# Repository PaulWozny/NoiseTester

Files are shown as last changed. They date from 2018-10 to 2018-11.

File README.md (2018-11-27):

## Noise tester for voltage regulators

Photo of noise tester
Close-up of noise tester

Borad and software required for tester of noise in power supplies.

This project created to show to show progress in my engineering thesis:

- PL: "Celem pracy jest opracowanie i zbudowanie niskoszumnego układu pozwalającego na pomiar szumów własnych liniowych stabilizatorów napięcia w paśmie do 1 MHz."
- EN: "The goal is to create low noise device which will allow mesure noise of the linear regulatores up to 1MHz"

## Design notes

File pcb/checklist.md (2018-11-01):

### PCB design chcecklist

This document provides reference to evaluate pcb design
 ---
##Design
1. Design is constrained
asdasdas
1.1 asdasd
 
##Schematic 

- All IC are validatated by 
-TX/RX pins are correctly assigned

##PCB
###Footprint
- relay's footprint is not inverted 

###Board
- clerance of PCB shield is sufficient with respect to other components
- testpoint have removed soldermask

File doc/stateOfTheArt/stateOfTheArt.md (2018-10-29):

# Measuring Noise in Voltage Regulators

#### Paweł Woźny </br> Faculty  of Electronics and Telecommunication, AGH 
---

#### Introduction
Following presentation will cover state of the art in current methods of measuring noise generated by regulators. 
In addition, current progress of my work will be shown.

Agenda:

1. What is voltage regulator?
2. What noise regulators have?
3. How to combat them?
4. My progress.

#### Voltage regulator
> is a device which converts unregulated supply to more or less stable output.

Simple regulator with opamp:

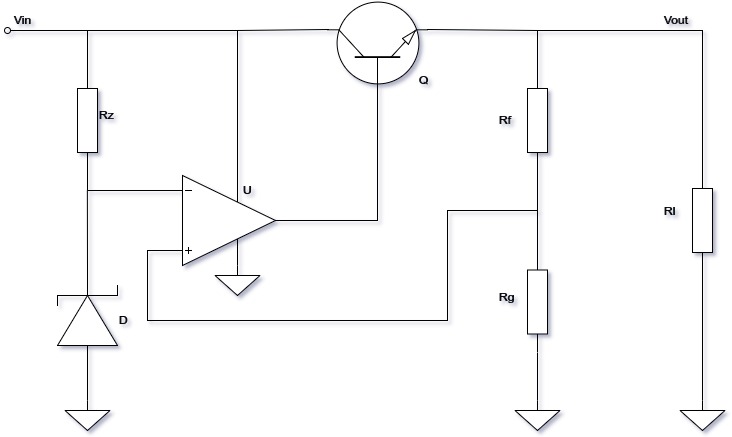
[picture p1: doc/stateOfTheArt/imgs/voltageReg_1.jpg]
aaa


##### Theory of operation

- Voltage reference.
- Feedback network.
- Error amplifier.
- Output stage.
 
#### Sources of noise in circuit

- Intrinsic semiconductor's noises:
    - popcorn noise,
    - shot noise,
    - 1/f (pink)noise.
    - Thermal noise (Johnson, wide-band, white) 
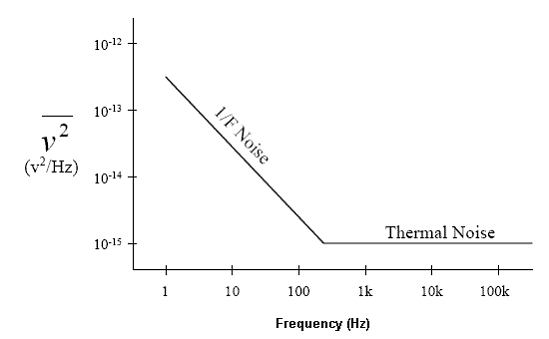
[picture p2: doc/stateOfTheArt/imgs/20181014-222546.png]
    
- Effect of temperature dependency.
- Seebeck (Thermoelectric effect).
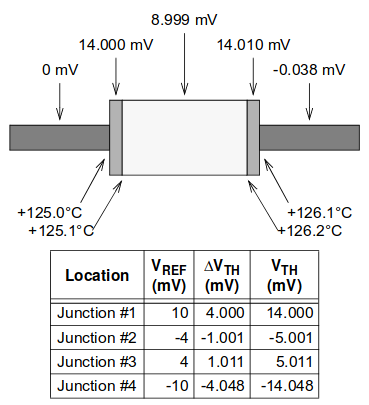
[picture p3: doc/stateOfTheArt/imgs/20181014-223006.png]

- Electromagnetic coupling
- Piezoelectric effects

### Mitigation of noise
- Improving process of lithography.
- Using dynamic offset cancelation (chopper amplifier).
- Using smaller value of resistance:
    - 600 Ohm resistor, 1kHz BW: 0.098uV RMS
    - 50 Ohm resistor, 1kHz BW: 0.0089uV RMS
- Derating elements.
- Filtering the reference:
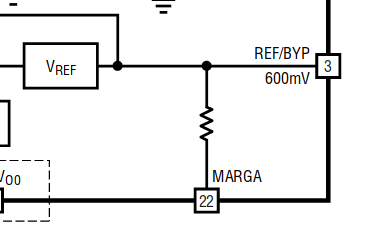
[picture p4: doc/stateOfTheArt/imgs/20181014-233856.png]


### State of the art
Simplified block diagram:


Fully fledged block diagram:
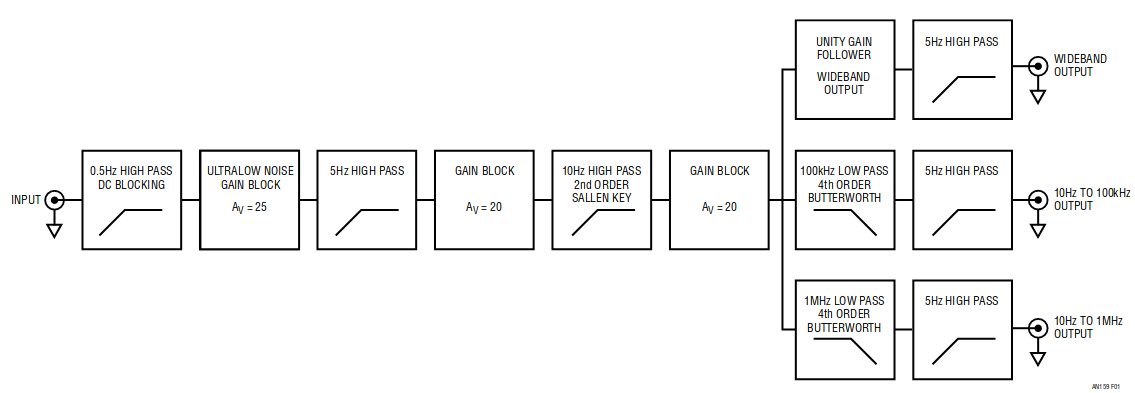
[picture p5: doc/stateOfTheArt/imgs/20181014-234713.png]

</br>

First stage of amplifier:
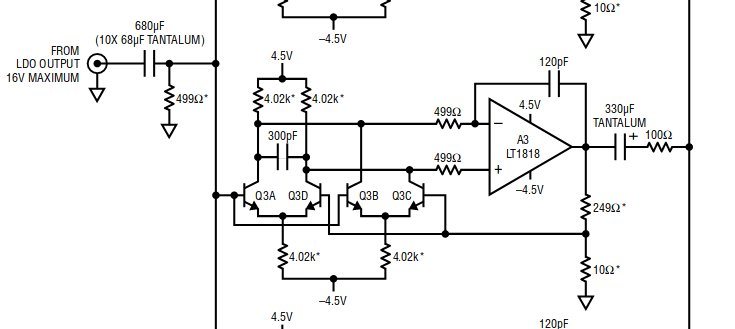
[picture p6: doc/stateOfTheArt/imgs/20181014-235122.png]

</br>

My adaptation:
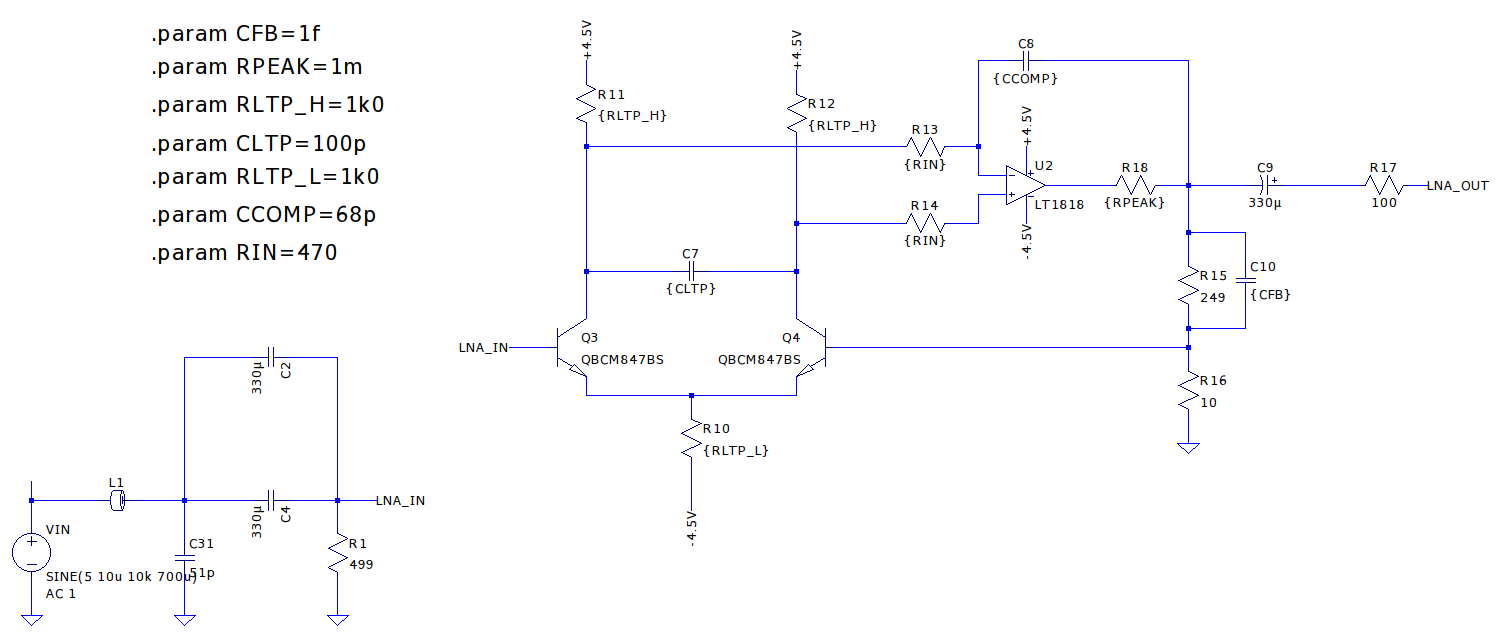
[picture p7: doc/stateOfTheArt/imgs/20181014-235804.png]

</br>

Stability of amplifier:
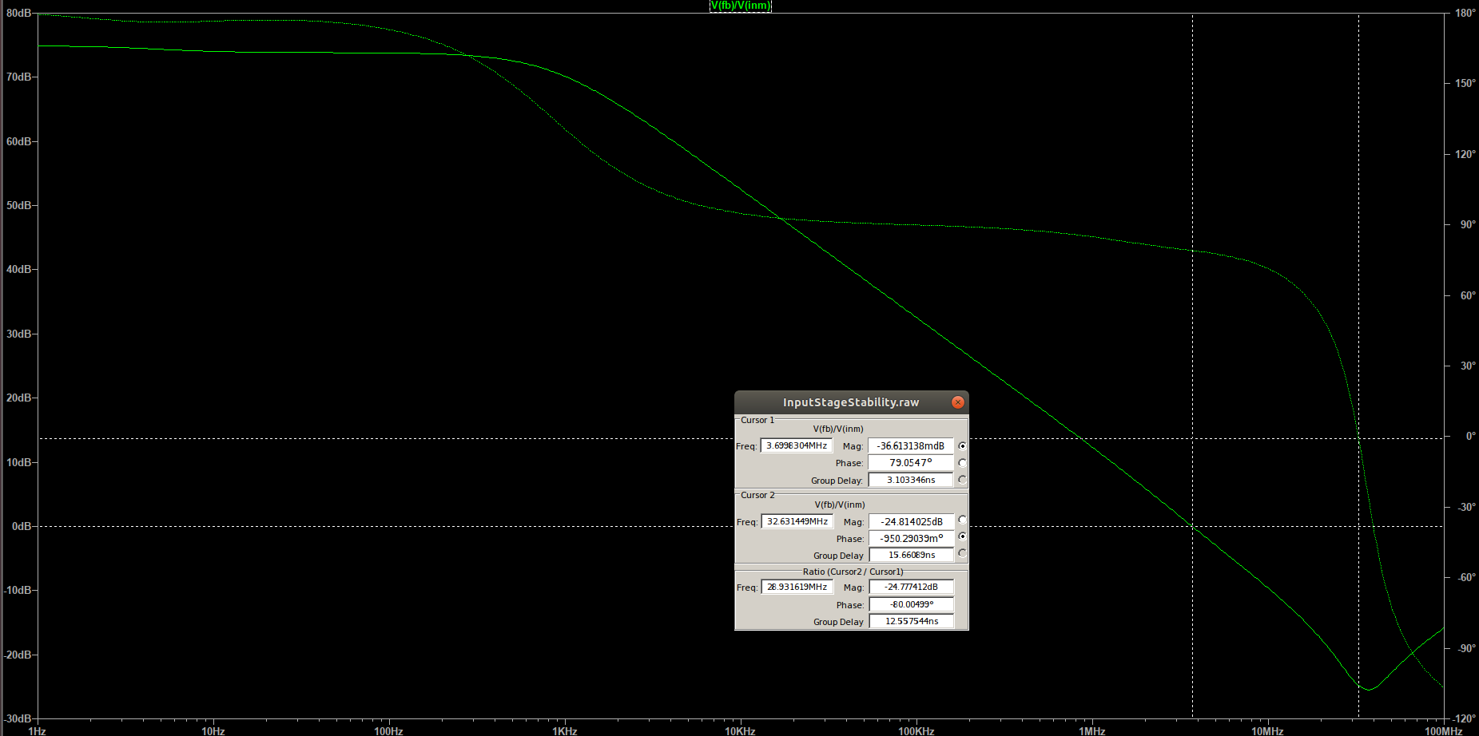
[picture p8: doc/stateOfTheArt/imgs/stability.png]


transfer Function:
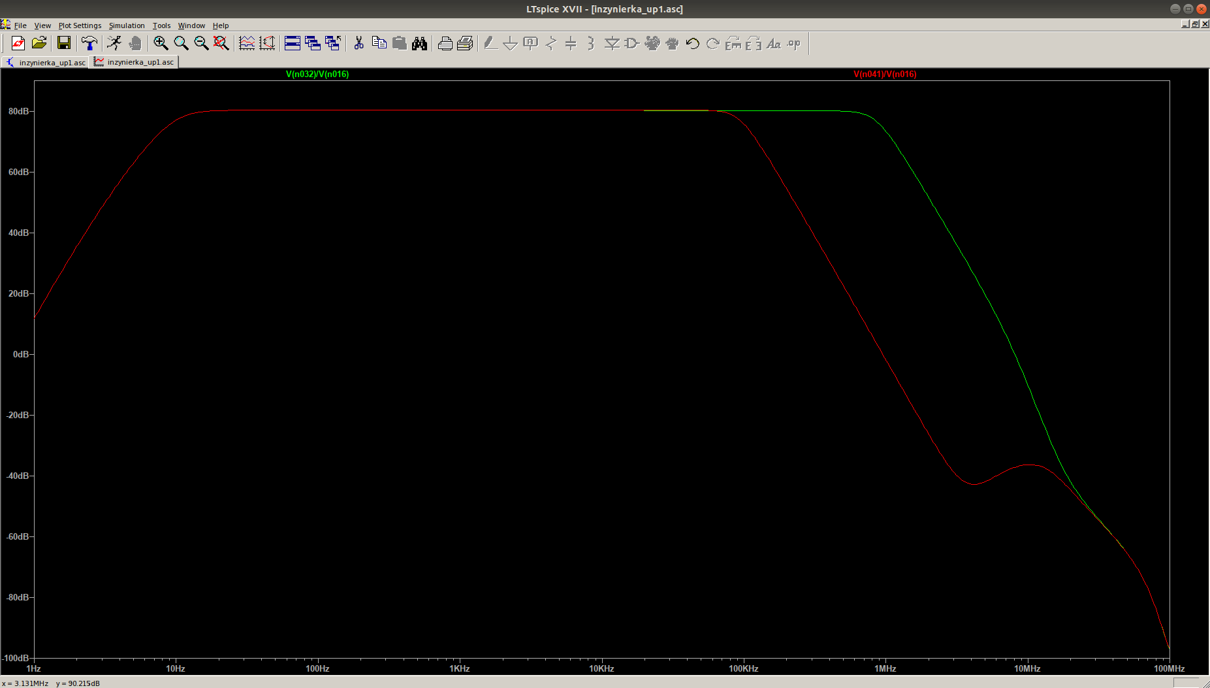
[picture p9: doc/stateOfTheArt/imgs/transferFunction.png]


### ToDo:
- Order components
- create and validate layout
- perform meauserments

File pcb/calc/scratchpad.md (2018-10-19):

#### Nonconstraint text which allow me to convey my thoughts
---
First try: to create discrete analog input stage

https://www.byteparadigm.com/files/documents/Using-SPI-Protocol-at-100MHz.pdf

https://www.ebay.com/itm/DC-DC-Boost-Step-Up-Isolated-Volt-Converter-5V-to-12V-125mA-Power-Supply-Module/323418069670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

http://www.analog.com/media/en/technical-documentation/application-notes/an83f.pdf,

http://www.ti.com/lit/an/snoa387c/snoa387c.pdf

https://www.allaboutcircuits.com/technical-articles/understanding-noise-and-psrr-in-ldos/

http://www.ti.com/lit/ds/symlink/opa1611.pdf

http://www.ti.com/lit/an/slyt133/slyt133.pdf

very useful:
http://www.ti.com/lit/wp/slyy076/slyy076.pdf

po prostu sie nie da uzyc zewnetrznego adc:

- szybki ADC (>40Mbit/s) wymaga szybkiego interfejsu. Niezawodność dostarczania próbek może zapewnić tylko STM
- parę wolnych adceków można zrównoleglić i sterować za pomocą rpi0. tylko tam opóźnienie linuxa jest kurwą i nie otrzyma się powtarzalnych wyników.
- adcek zintegrowany w stm32 będzie szumił, a do tego będzie problem z izolacją toru pomiarowego

Moja propozycja:

- Rpi0 łączy się z FTDI HS, który łączy się przez izolator z ADC przez SPI, który jest sterowany z AFE. FTDI wyprowadza gpio potrzebne do sterowania afe

lub:

- afe - adc - iso - stm32/w usb, ram, sd

pierdułki dla kicada
https://knowledge.autodesk.com/support/autocad-electrical/learn-explore/caas/CloudHelp/cloudhelp/2019/ENU/AutoCAD-Electrical/files/GUID-7871E6EF-24D5-467E-9B74-321FE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

---
tutaj należałoby skomasować swoje przemyślenia:
xxxxx
---
4.10.2018

Pod tym linkiem znajduje się ulepszona wersja układu od jima:
http://www.analog.com/media/en/technical-documentation/application-notes/an159fa.pdf

- Mają drogie tranzystory na stopniu wejściowym: THAT300A. kosztuje około 45plz/sztukę, a potrzeba przynajmniej 4.
Łączą dwie pary różnicowe równolegle. W pdfie pd czecha {{}}} było pokazane, że to może wpłynąć negatywnie na {{{{{}}}}}
- Sama para różnicowa jest mocno dopasowane. Ciekawe czy dałoby się użyć tańszych elementów przy zastosowaniu aktywnej kompensacji, jak tutaj:
http://www.analog.com/media/en/technical-documentation/application-notes/an124f.pdf
Na przykład 
- Używają kondensatory tantalowe, które nie mają efektu piezo. Tylko trzeba uważać, żeby nie wybuchły

Porównując dshety:
https://assets.nexperia.com/documents/data-sheet/BCM847BV_BS_DS.pdf
oraz
http://www.thatcorp.com/datashts/THAT_300-Series_Datasheet.pdf
wychodzi na to, że aż tak bardzo się nie różnią. THAT300 ma dopasowanie hfe na poziomie 4% vs 10% od BCM847BV, natomiast dopasowanie VBE THAT300 ma 3mV max z 0.5 typowym, a BCM847 ma** 2mV MAX**.

---
6.10.2018

Stworzyłem cały schemat dla wzmacniacza. Od razu wiedzę --2-- trzy problemy

- Obudowa. Jeżeli będzie zrobiona ze stali (a stal jest najtańsza) to ścianka musi być gruba na 10-15mm
https://allegro.pl/blacha-stalowa-10-mm-cieta-na-wymiar-i6728885673.html
- stabilność wzmacniacza. Jest dużo stopni wzmacniacza i każdy może oscylować. ;/
- małe napięcie wyjsciowe. Napięcie wyjściowe dla wejścia 1uV wynosi 10mV. przydałyby się kolejne stopnie wzmocniania dla obróbki z ADCkiem

Zasilanie bateryjne mogą zapewnić baterie R20.
https://allegro.pl/koszyk-na-baterie-3xr20-plaski-i7416083768.html 

Tranzystory uzyte przeze mnie mają inne pojemności od THATowych. PRzez co musiałem pozmieniać układ

Czy dwa kondensatory tantalowe 330uF będą miały takie same (albo przynajmniej wystarczające) właściwośći przy granicy 1MHz?
TAJE337M016RNJ

Zamiast 2 330stek można użyć trzy 220uF

Albo 100u faradowe:  T491D107K020AT (dostępne w TME)

Koszt samych  kondensatorów to około 100pln

---
7.10.2018

Skoczyłem układ. No nie do końca bo jest niestabilny. Przy dodaniu czwartego stopnia wejściowego dostaje oscylacji koło 13MHz. Zrobiłem projekt ze samym stopniem wejściowym i zaczynam poszukiwania
Wygląda na to, że gdy podłączam wejście od 4. układu to całość dostaje pierdolca.
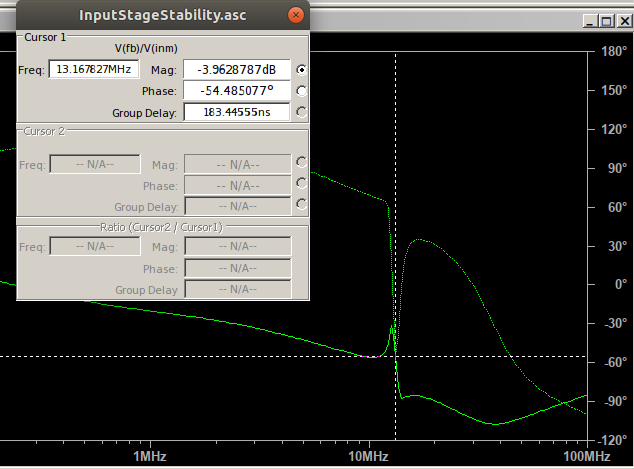
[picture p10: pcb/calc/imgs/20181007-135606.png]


Problem okazał się dolny rezystor. Zmiana z 1k do 3k pomogła.
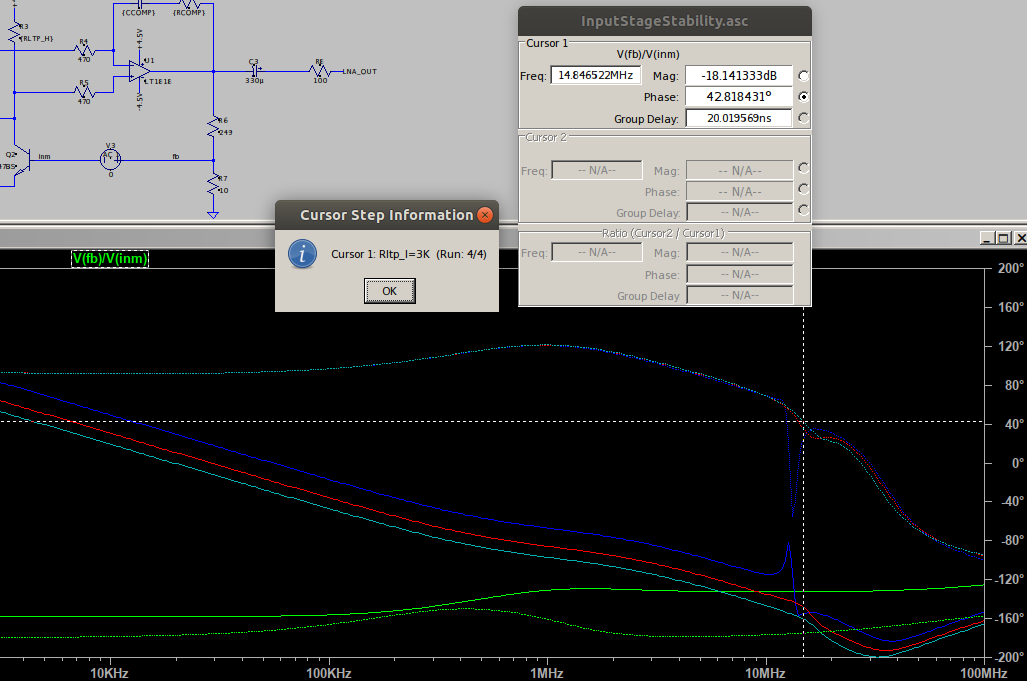
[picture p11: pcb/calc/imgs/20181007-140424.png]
 

Udało się! Nie oscyluje i ma xxx marginesu

Podczas Różnorakich testów można było zauważyć, że łatwo nasycić wzmacniacz. Może dodać możliwość zmiany wzmocnienia ostatniego bloku?
 
 - 100Ohm/2k
 - 100Ohm/100Ohm
 
 Symulacja tran dla przemiatanej czestotliwości wykazała, że wzmocnienie spada ?liniowo? ze wzrostem czestotliowści. Dla f=650kHz wzmocnienie było równe tylko 0.560 wartości początkowej.
 
 Przez tą kompensacje przysiadło trochę wzmocnienie
 
 bawiąc się .tep zauważyłem, że można symulować do trzeb zmiennych jednocześnie. Fajnie by było jakbym znalazł możliwość automatycznego wybierania pożądanych charakterystyk; np w moim przypadku interesują mnie tylko te wartośći, dla których wzmocnienie przyy 1MHz jest równe 28dB
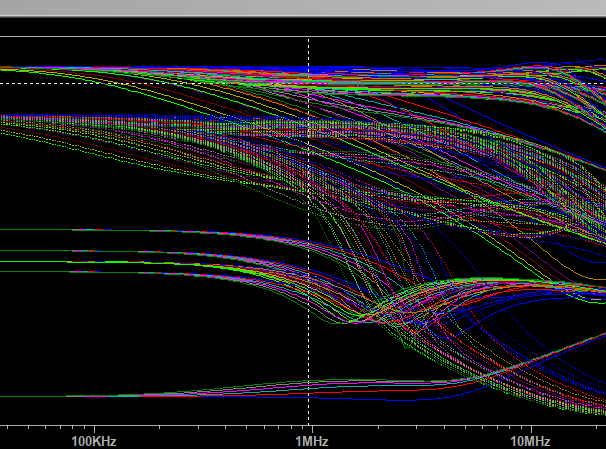
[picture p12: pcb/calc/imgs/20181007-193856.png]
 
 
 Ostateczny wynik stabilności:
 
 Schemat układu:
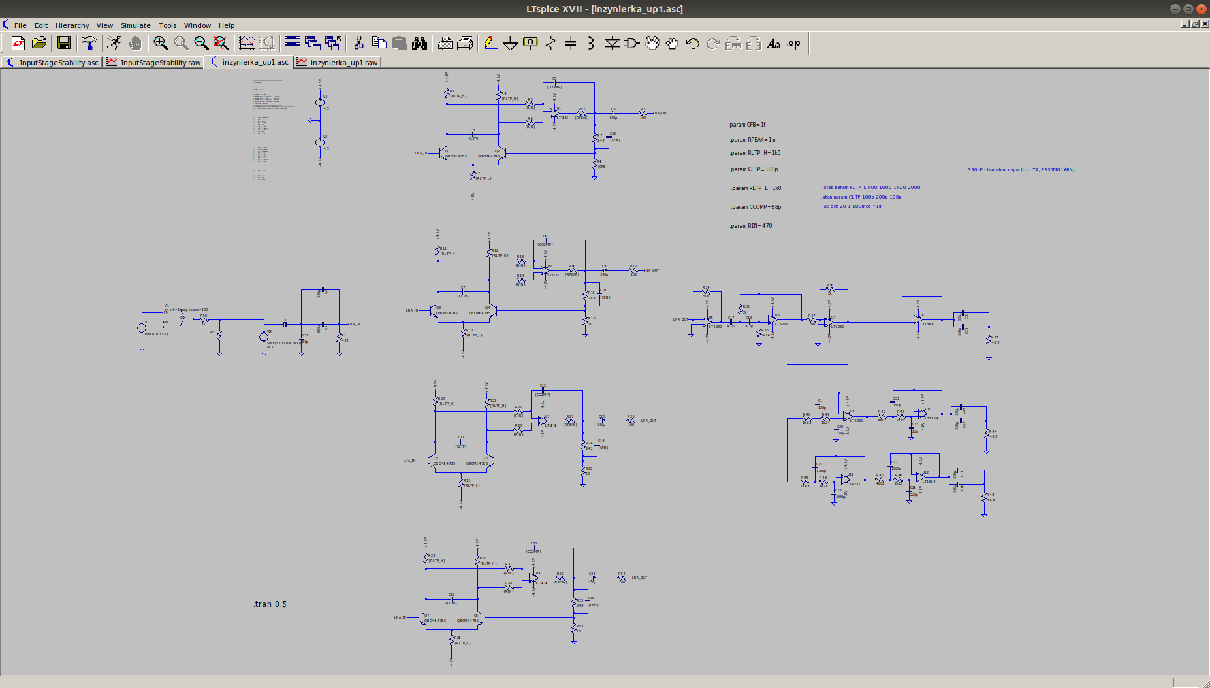
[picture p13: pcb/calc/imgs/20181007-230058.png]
 
 
 Lista zakupów:
 
 - precyzyjne rezystory 1k:  MORNTA1001AT5 - 4 sztuki
 - rezystory do FB 250Ohm/10Ohm: Coś z elpoda 0.25%/10ppm 4 sztuki
 asd

 as

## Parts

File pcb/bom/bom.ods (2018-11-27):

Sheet: BOM
co | ilosć | cena jed | razem | skąd
Tantale 220uF | 60 | 0,615 | 36,9 | https://allegro.pl/10szt-220uf-10v-d-tantal-smd-kondensator-s-m-i7288054184.html
LT1364CS8 | 5 | 11 | 55 | https://allegro.pl/lt1364cs8-soic8-i7589381160.html
LT1818 | 5 | 7,8 | 39 | digikey
LT6232 | 3 | 31,2 | 93,6 | digikey
 |  |  | 0
 |  |  | 0
 |  |  | 0
 |  |  | 0
 |  |  | 0
 |  |  | 0
 |  |  | 0
 |  |  | 0
 |  |  | 0
 |  |  | 0
 |  |  | 0
 |  |  | 0
suma |  |  | 224,5

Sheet: paid
Tantals 220uF | 45,89
LT1364 | 63,99
koszyk na R20 | 32,19
PCB | 250
Elementy | 277
suma | 669,07

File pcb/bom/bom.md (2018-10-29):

# niedziela, 28. października 2018 08:49

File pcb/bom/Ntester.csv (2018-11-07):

Id | Designator | Package | Quantity | Designation | Supplier and ref
1 | J6,J3,J2,J5 | BNC_TEConnectivity_1478204_Vertical | 4 | 5-1634503-1
4 | R36,R31,R26,R2 | R_0603_1608Metric | 4 | RNCF0603AKT10R0
5 | C77,C66,C55,C8 | R_0603_1608Metric | 4 | 885012006038
6 | C86,C87,C78,C80,C75,C76,C69,C67,C56,C58,C64,C65,C41,C40,C27,C26,C21,C20,C5,C4,C16,C15,C11,C10 | R_0603_1608Metric | 24 | 0603B104M500CT
7 | R34,R33,R29,R28,R23,R24,R5,R4 | R_0603_1608Metric | 8 | CR0603-JW-471ELF
8 | C79,C68,C57,C44,C43,C2,C9 | R_0603_1608Metric | 7 | 885012006007
9 | RN4,RN3,RN2,RN1 | R_Array_Convex_4x1206 | 4 | ACASA1001S1001P1AT
12 | R35,R30,R25,R1 | R_0603_1608Metric | 4 | RNCF0603TKY250R
13 | Q4,Q3,Q2,Q1 | SOT-363_SC-70-6 | 4 | BC847BDW1T1G
14 | R37,R32,R27,R6 | R_0603_1608Metric | 4 | RG1608N-101-W-T1
15 | U7,U6,U5,U1 | SOIC-8-LINEAR | 4 | LT1818
16 | C47,C54,C53,C52,C51,C50,C49,C48,C46,C45,C38,C37,C36,C35 | C_1210_3225Metric | 14 | GRM32ER60J107ME20K
22 | SW1 | SW_CuK_JS202011CQN_DPDT_Straight | 1 | JS202011CQN
23 | C29,C24 | CAP-6054-SMDTD04470YA00MT00 | 2 | SMDTD04470YA00MT00
26 | D4,D3,D2,D1 | SOT-23 | 4 | BAS116LT1G
28 | R3 | R_2512_6332Metric | 1 | RHC2512FT4R99
29 | R9,R10 | R_0603_1608Metric | 2 | RMCF0603FT499R
30 | U3,U2 | SOIC-8-LINEAR | 2 | LT6231
31 | R8 | R_1206_3216Metric | 1 | CR1206-FX-4990ELF
32 | R7 | R_2512_6332Metric | 1 | CRM2512-JW-470ELF
36 | FB1 | R_0603_1608Metric | 1 | 742792651
39 | J7 | Wuerth_36503505_50x50mm | 1 | 36503505S
 |  |  |  | 36003500S

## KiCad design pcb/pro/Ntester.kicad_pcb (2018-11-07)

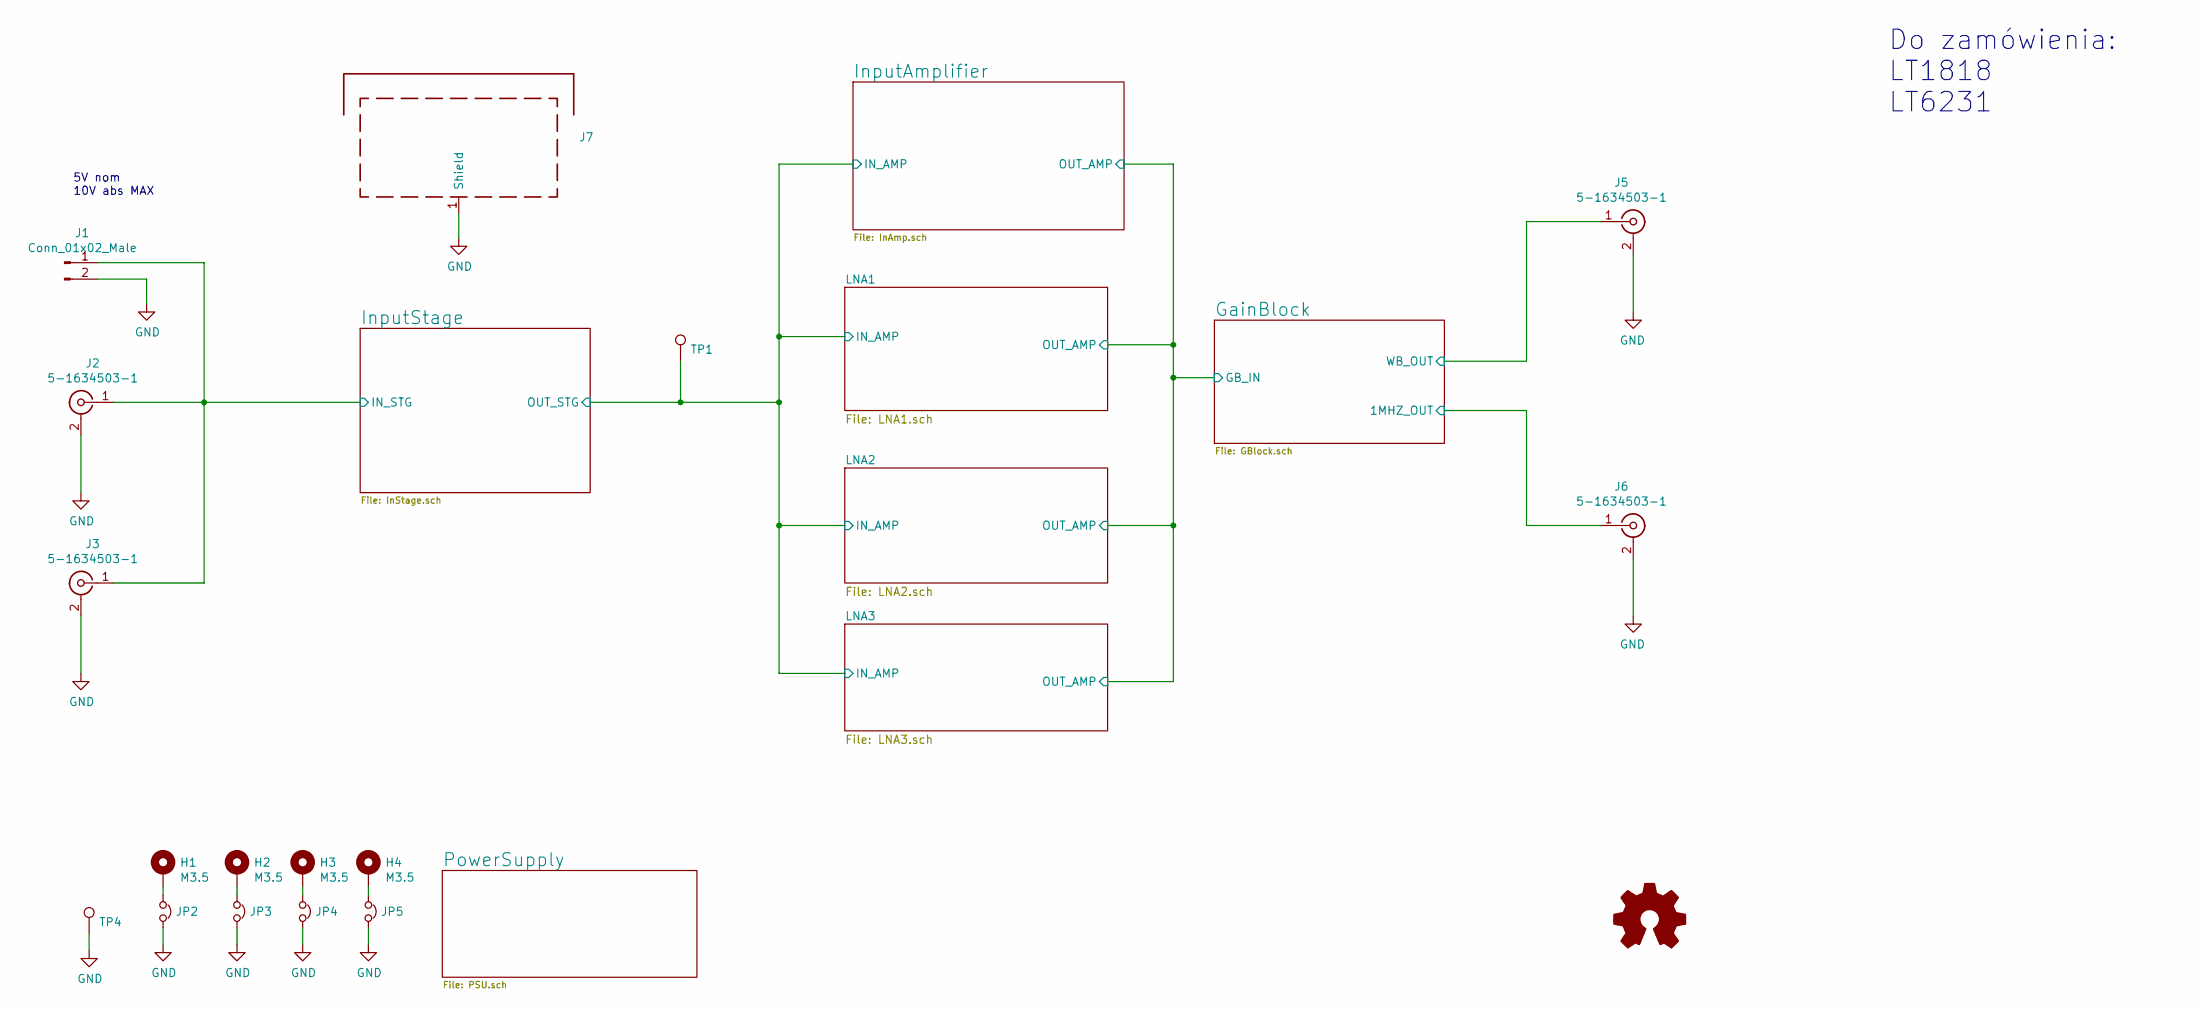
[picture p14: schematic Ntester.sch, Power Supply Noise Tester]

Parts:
H1, H2, H3, H4: M3.5; MountingHole_3.5mm_Pad_Via
J1: Conn_01x02_Male; PinHeader_1x02_P2.54mm_Vertical
J2, J3, J5, J6: 5-1634503-1; BNC_TEConnectivity_1478204_Vertical
J7: 36503505S 36003500S; Wuerth_36503505_50x50mm
JP2, JP3, JP4, JP5: GND_SHIELD; SolderJumper-2_P1.3mm_Open_TrianglePad1.0x1.5mm
TP1, TP4: TestPoint; TestPoint_THTPad_D1.0mm_Drill0.5mm

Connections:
/GainBlock/1MHZ_OUT: J6.1 (In); also elsewhere on the board
/GainBlock/WB_OUT: J5.1 (In); also elsewhere on the board
/InputAmplifier/IN_AMP: TP1.1; also elsewhere on the board
/InputStage/IN_STG: J1.1, J2.1 (In), J3.1 (In); also elsewhere on the board
GND: J1.2, J2.2 (Ext), J3.2 (Ext), J5.2 (Ext), J6.2 (Ext), J7.1, JP2.2, JP3.2, JP4.2, JP5.2, TP4.1; also elsewhere on the board
unnamed: H1.1, JP2.1
unnamed: H2.1, JP3.1
unnamed: H3.1, JP4.1
unnamed: H4.1, JP5.1

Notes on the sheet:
5V nom 10V abs MAX
Do zamówienia: LT1818 LT6231

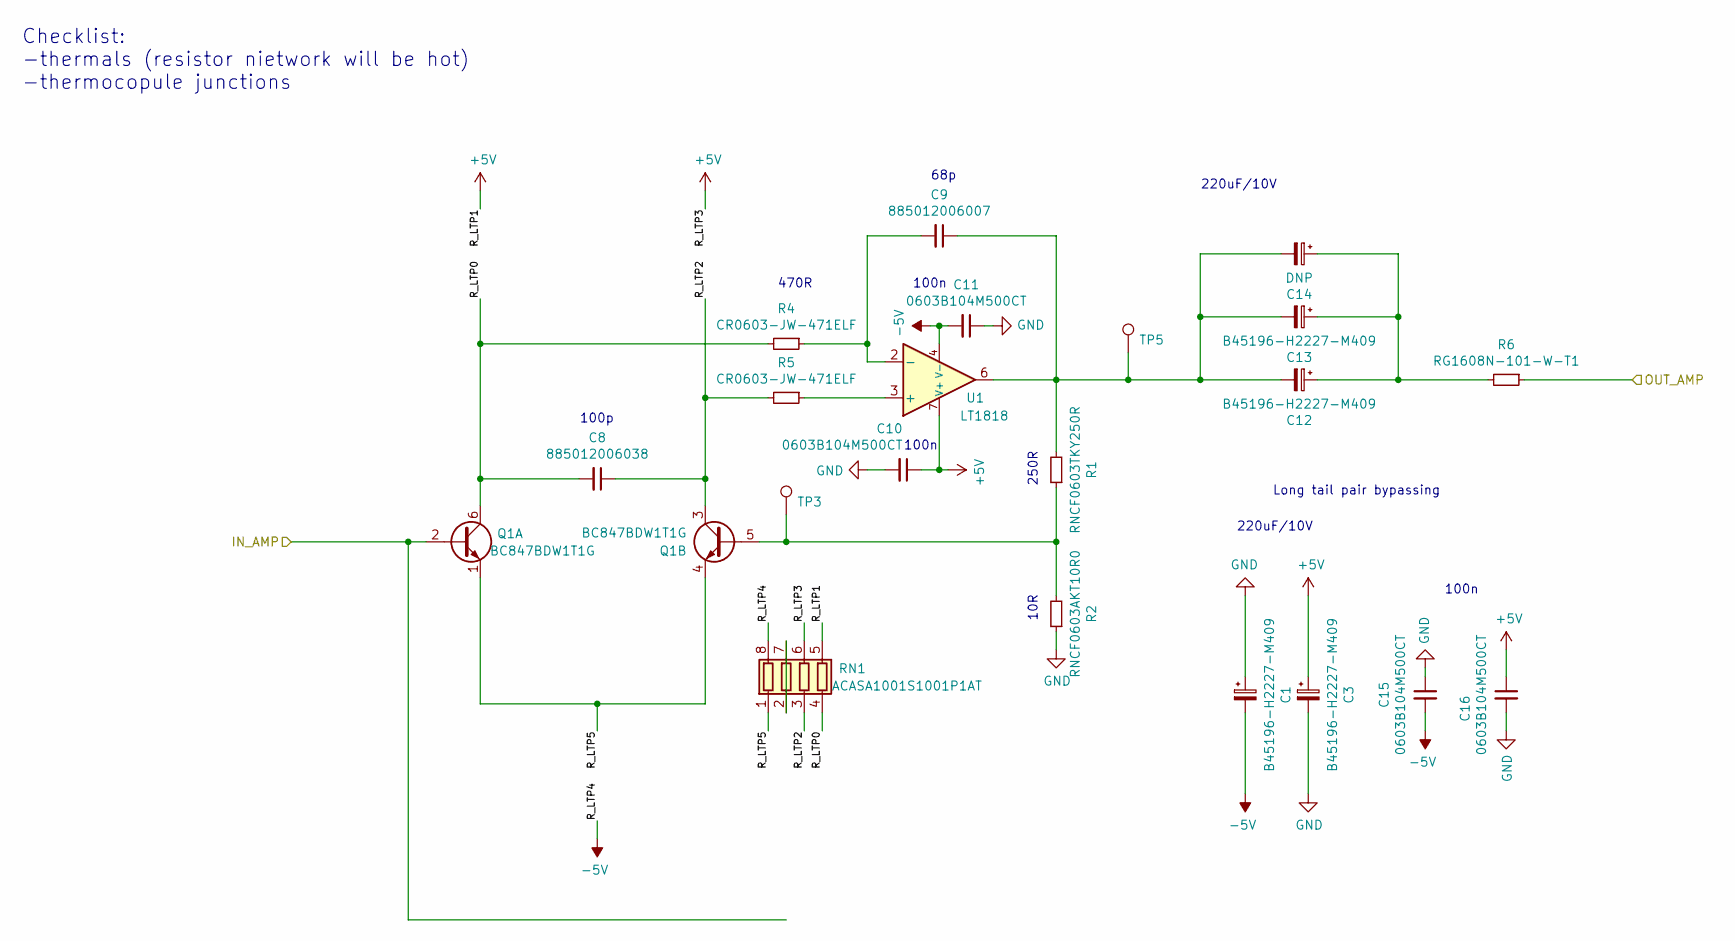
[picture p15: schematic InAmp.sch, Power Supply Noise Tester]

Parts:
C1, C3, C12, C13: B45196-H2227-M409; CP_EIA-7343-31_Kemet-D
C8: 885012006038; R_0603_1608Metric
C9: 885012006007; R_0603_1608Metric
C10, C11, C15, C16: 0603B104M500CT; R_0603_1608Metric
C14: DNP; CP_EIA-7343-31_Kemet-D
Q1: BC847BDW1T1G; SOT-363_SC-70-6
R1: RNCF0603TKY250R; R_0603_1608Metric
R2: RNCF0603AKT10R0; R_0603_1608Metric
R4, R5: CR0603-JW-471ELF; R_0603_1608Metric
R6: RG1608N-101-W-T1; R_0603_1608Metric
RN1: ACASA1001S1001P1AT; R_Array_Convex_4x1206
TP3, TP5: TestPoint; TestPoint_THTPad_D1.0mm_Drill0.5mm
U1: LT1818; SOIC-8-LINEAR

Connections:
+5V: C3.1, C10.1, C16.1, RN1.5 (R4.2), RN1.6 (R3.2), U1.7 (V+); also elsewhere on the board
-5V: C1.2, C11.2, C15.2, RN1.8 (R1.2), U1.4 (V-); also elsewhere on the board
/GainBlock/GB_IN: R6.1; also elsewhere on the board
/InputAmplifier/IN_AMP: Q1.2 (B1); also elsewhere on the board
/InputAmplifier/R_LTP0: C8.2, Q1.6 (C1), R4.2, RN1.4 (R4.1)
/InputAmplifier/R_LTP2: C8.1, Q1.3 (C2), R5.2, RN1.3 (R3.1)
/InputAmplifier/R_LTP5: Q1.1 (E1), Q1.4 (E2), RN1.1 (R1.1)
GND: C1.1, C3.2, C10.2, C11.1, C15.1, C16.2, R2.1; also elsewhere on the board
unnamed: C9.2, R4.1, U1.2 (-)
unnamed: C12.1, C13.1, C14.1, R6.2
unnamed: C9.1, C12.2, C13.2, C14.2, R1.2, TP5.1, U1.6
unnamed: Q1.5 (B2), R1.1, R2.2, TP3.1
unnamed: R5.1, U1.3 (+)

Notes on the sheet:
Checklist: -thermals (resistor nietwork will be hot) -thermocopule junctions
Long tail pair bypassing
100n
220uF/10V
68p
100p
470R
10R
250R

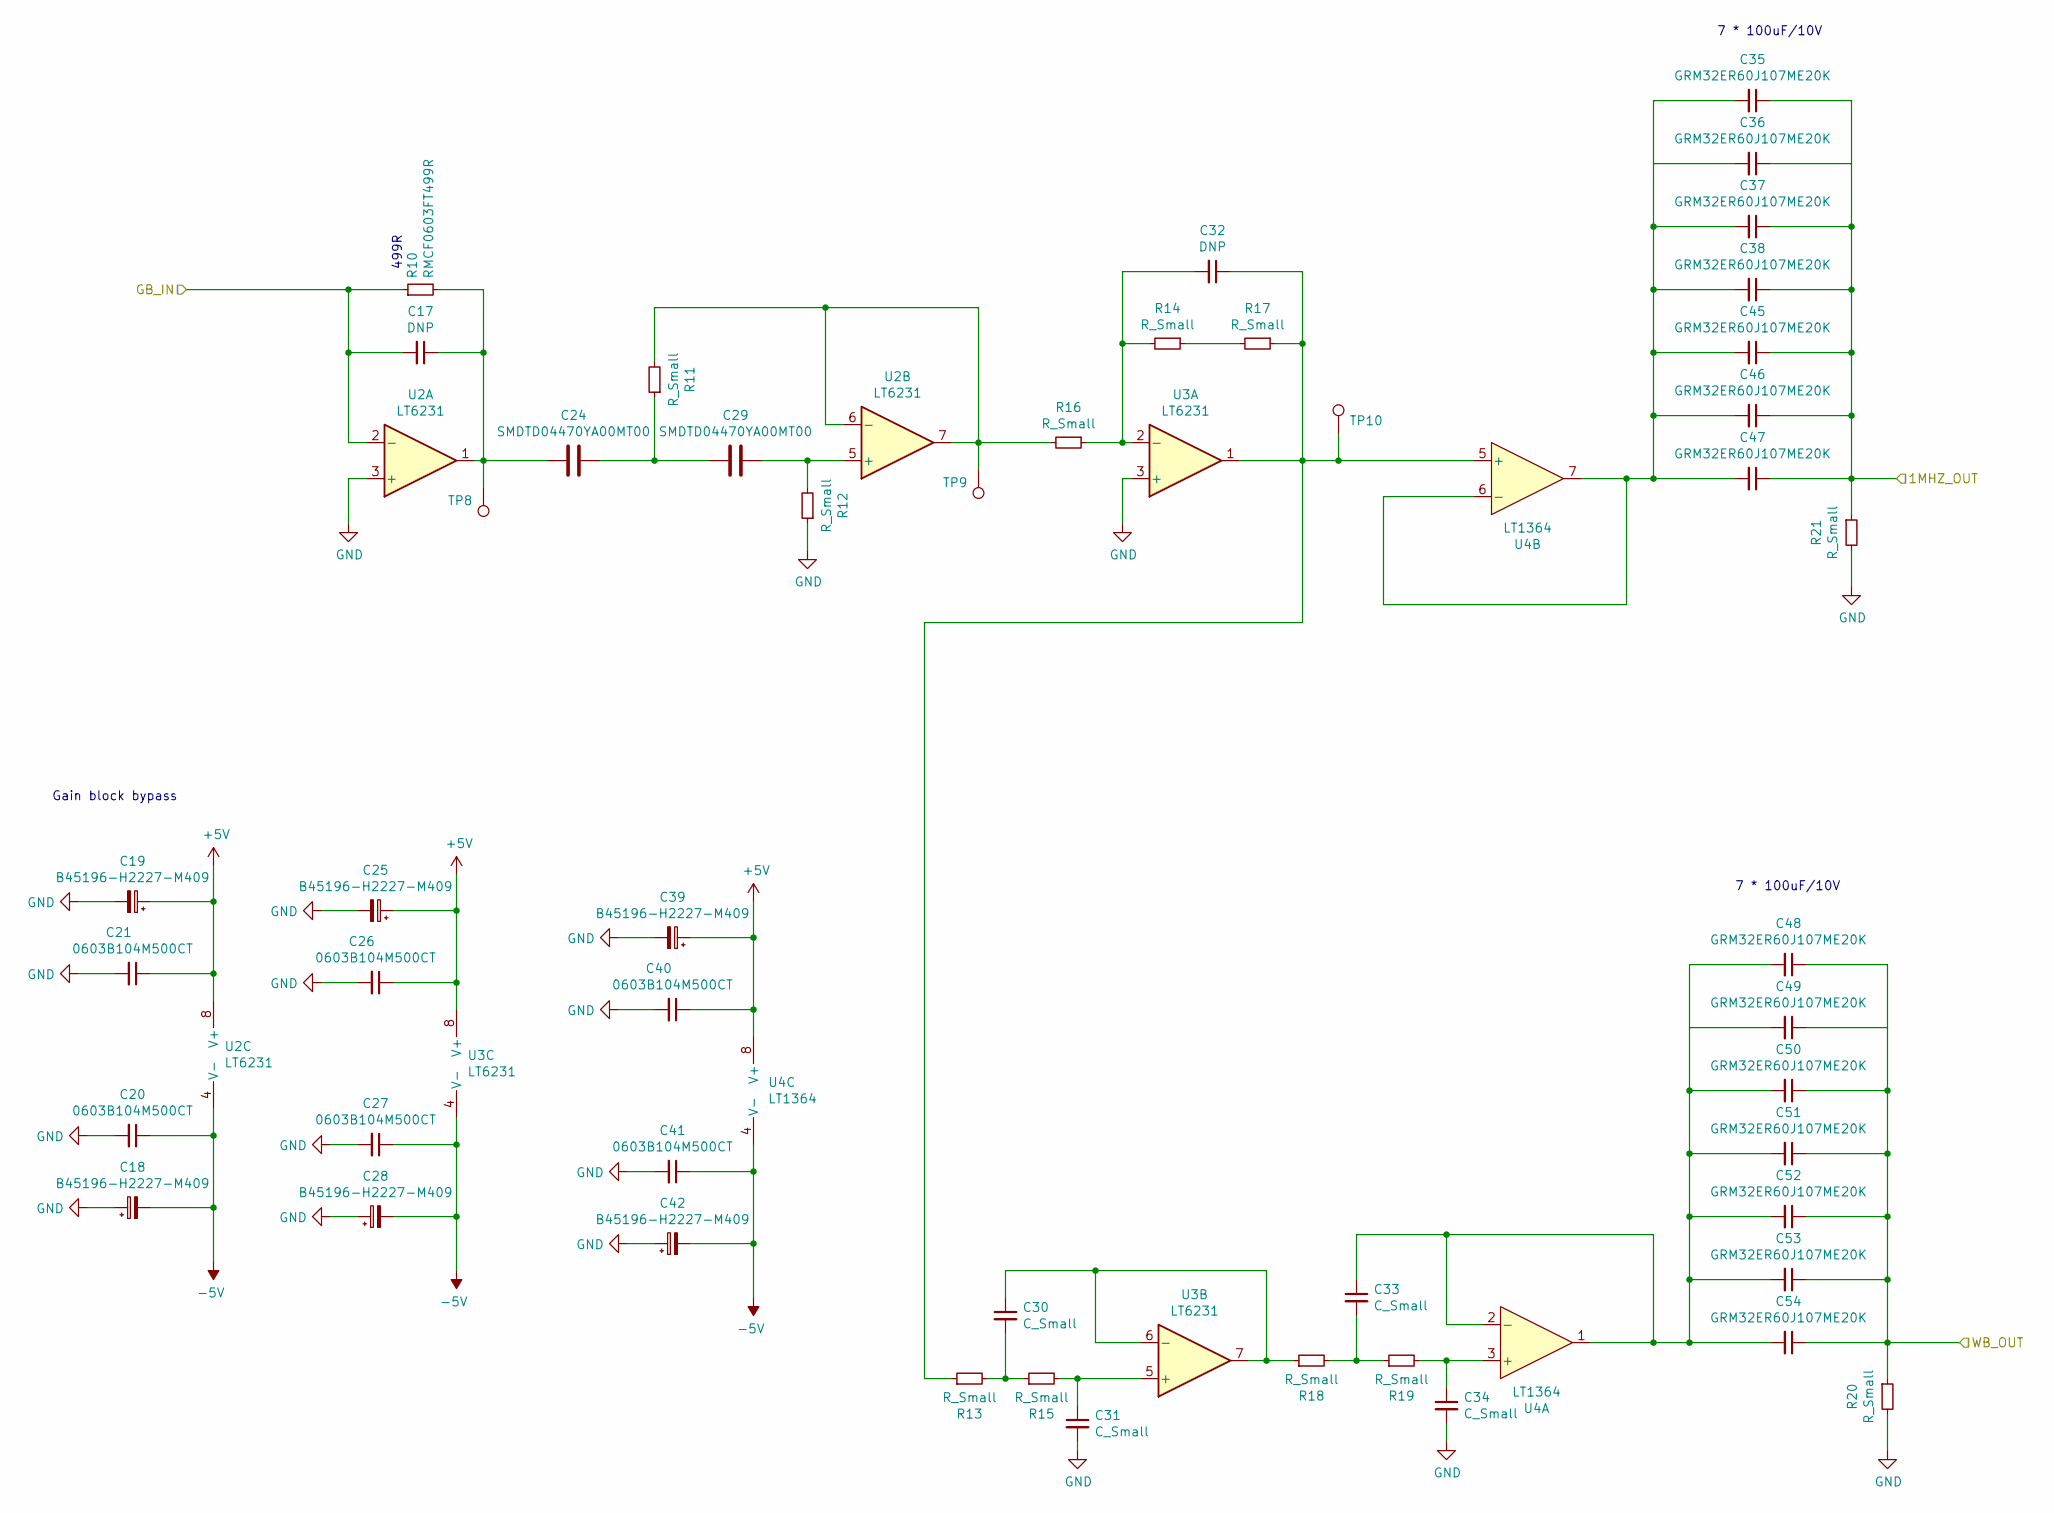
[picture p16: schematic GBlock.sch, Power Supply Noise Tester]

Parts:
C17, C32: DNP; C_0603_1608Metric
C18, C19, C25, C28, C39, C42: B45196-H2227-M409; CP_EIA-7343-31_Kemet-D
C20, C21, C26, C27, C40, C41: 0603B104M500CT; R_0603_1608Metric
C24, C29: SMDTD04470YA00MT00; CAP-6054-SMDTD04470YA00MT00
C30, C31, C33, C34: C_Small; C_0603_1608Metric
C35, C36, C37, C38, C45, C46, C47, C48, C49, C50, C51, C52, C53, C54: GRM32ER60J107ME20K; C_1210_3225Metric
R10: RMCF0603FT499R; R_0603_1608Metric
R11, R12, R13, R14, R15, R16, R17, R18, R19: R_Small; R_0603_1608Metric
R20, R21: R_Small; R_1206_3216Metric
TP8, TP9, TP10: TestPoint; TestPoint_THTPad_D1.0mm_Drill0.5mm
U2, U3: LT6231; SOIC-8-LINEAR
U4: LT1364; SOIC-8-LINEAR

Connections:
+5V: C19.1, C21.1, C25.1, C26.1, C39.1, C40.1, U2.8 (V+), U3.8 (V+), U4.8 (V+); also elsewhere on the board
-5V: C18.2, C20.1, C27.1, C28.2, C41.1, C42.2, U2.4 (V-), U3.4 (V-), U4.4 (V-); also elsewhere on the board
/GainBlock/1MHZ_OUT: C35.1, C36.1, C37.1, C38.1, C45.1, C46.1, C47.1, R21.1; also elsewhere on the board
/GainBlock/GB_IN: C17.2, R10.1, U2.2 (-); also elsewhere on the board
/GainBlock/WB_OUT: C48.1, C49.1, C50.1, C51.1, C52.1, C53.1, C54.1, R20.1; also elsewhere on the board
GND: C18.1, C19.2, C20.2, C21.2, C25.2, C26.2, C27.2, C28.1, C31.2, C34.2, C39.2, C40.2, C41.2, C42.1, R12.1, R20.2, R21.2, U2.3 (+), U3.3 (+); also elsewhere on the board
unnamed: C17.1, C24.2, R10.2, TP8.1, U2.1
unnamed: C24.1, C29.2, R11.1
unnamed: C29.1, R12.2, U2.5 (+)
unnamed: C30.1, R18.1, U3.6 (-), U3.7
unnamed: C30.2, R13.2, R15.1
unnamed: C31.1, R15.2, U3.5 (+)
unnamed: C32.1, R13.1, R17.1, TP10.1, U3.1, U4.5 (+)
unnamed: C32.2, R14.2, R16.1, U3.2 (-)
unnamed: C33.1, C48.2, C49.2, C50.2, C51.2, C52.2, C53.2, C54.2, U4.1, U4.2 (-)
unnamed: C33.2, R18.2, R19.1
unnamed: C34.1, R19.2, U4.3 (+)
unnamed: C35.2, C36.2, C37.2, C38.2, C45.2, C46.2, C47.2, U4.6 (-), U4.7
unnamed: R11.2, R16.2, TP9.1, U2.6 (-), U2.7
unnamed: R14.1, R17.2

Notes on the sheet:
Gain block bypass
499R
7 * 100uF/10V

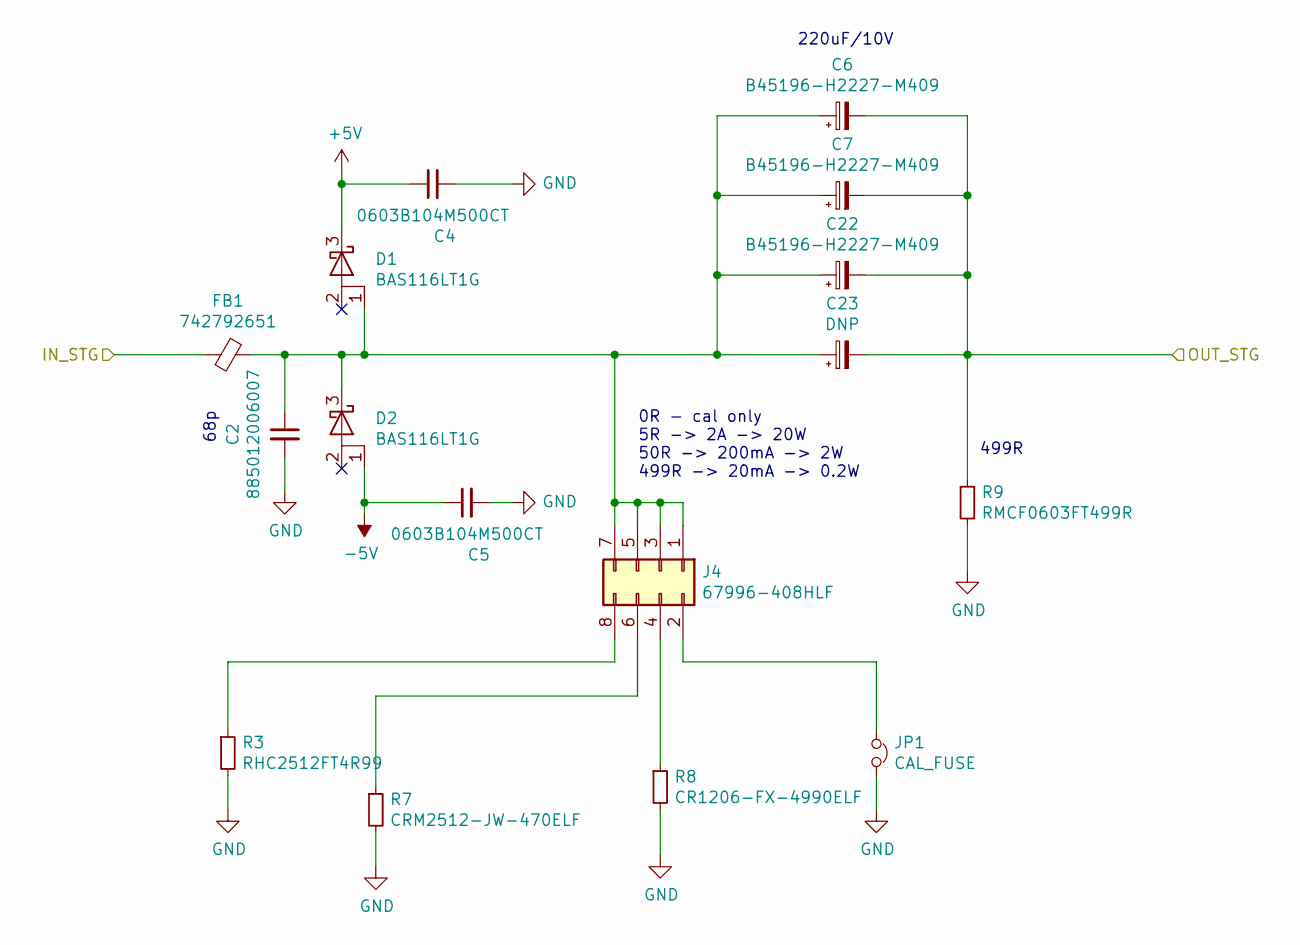
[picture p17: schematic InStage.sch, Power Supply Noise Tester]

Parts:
C2: 885012006007; R_0603_1608Metric
C4, C5: 0603B104M500CT; R_0603_1608Metric
C6, C7, C22: B45196-H2227-M409; CP_EIA-7343-31_Kemet-D
C23: DNP; CP_EIA-7343-31_Kemet-D
D1, D2: BAS116LT1G; SOT-23
FB1: 742792651; R_0603_1608Metric
J4: 67996-408HLF; PinHeader_2x04_P2.54mm_Vertical
JP1: CAL_FUSE; SolderJumper-2_P1.3mm_Bridged_Pad1.0x1.5mm
R3: RHC2512FT4R99; R_2512_6332Metric
R7: CRM2512-JW-470ELF; R_2512_6332Metric
R8: CR1206-FX-4990ELF; R_1206_3216Metric
R9: RMCF0603FT499R; R_0603_1608Metric

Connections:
+5V: C4.1, D1.3 (K); also elsewhere on the board
-5V: C5.1, D2.1 (A); also elsewhere on the board
/InputAmplifier/IN_AMP: C6.2, C7.2, C22.2, C23.2, R9.1; also elsewhere on the board
/InputStage/IN_STG: FB1.2; also elsewhere on the board
GND: C2.2, C4.2, C5.2, JP1.2, R3.2, R7.2, R8.2, R9.2; also elsewhere on the board
unnamed: C2.1, C6.1, C7.1, C22.1, C23.1, D1.1 (A), D2.3 (K), FB1.1, J4.1, J4.3, J4.5, J4.7
unnamed: J4.2, JP1.1
unnamed: J4.4, R8.1
unnamed: J4.6, R7.1
unnamed: J4.8, R3.1

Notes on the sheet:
220uF/10V
68p
499R
0R - cal only 5R -> 2A -> 20W 50R -> 200mA -> 2W 499R -> 20mA -> 0.2W

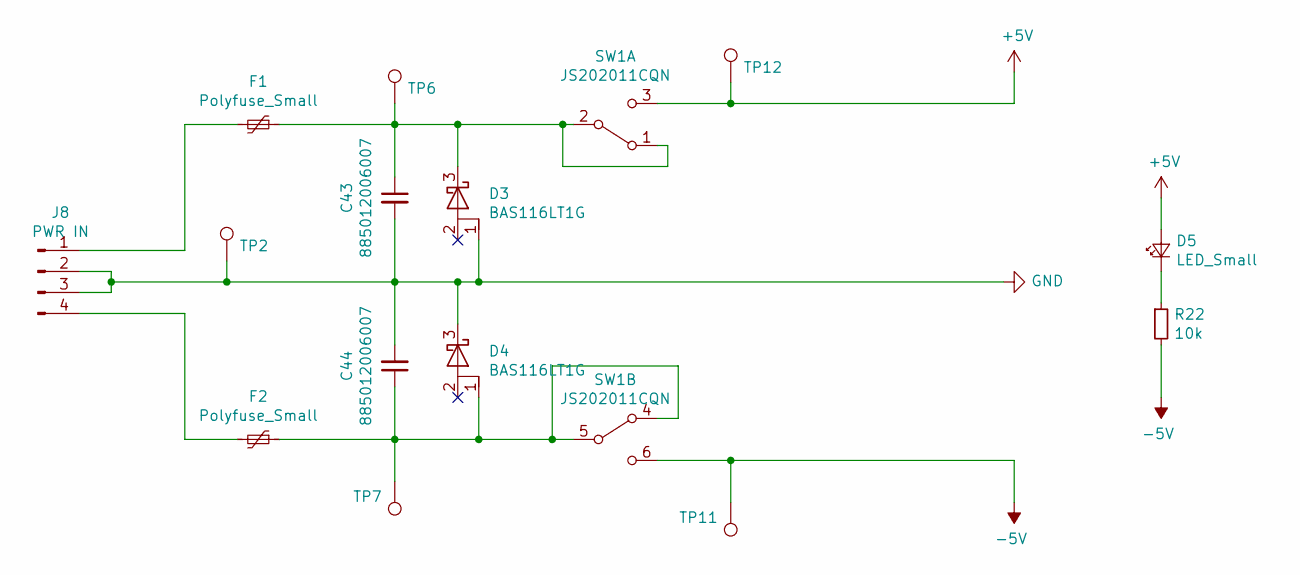
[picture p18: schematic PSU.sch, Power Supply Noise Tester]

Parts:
C43, C44: 885012006007; R_0603_1608Metric
D3, D4: BAS116LT1G; SOT-23
D5: LED_Small; R_0805_2012Metric
F1, F2: Polyfuse_Small; R_0805_2012Metric
J8: PWR IN; PinHeader_1x04_P2.54mm_Vertical
R22: 10k; R_0805_2012Metric
SW1: JS202011CQN; SW_CuK_JS202011CQN_DPDT_Straight
TP2, TP6, TP7, TP11, TP12: TestPoint; TestPoint_THTPad_D1.0mm_Drill0.5mm

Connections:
+5V: D5.2 (A), SW1.3 (C), TP12.1; also elsewhere on the board
-5V: R22.2, SW1.6 (C), TP11.1; also elsewhere on the board
GND: C43.2, C44.2, D3.1 (A), D4.3 (K), J8.2, J8.3, TP2.1; also elsewhere on the board
unnamed: C43.1, D3.3 (K), F1.1, SW1.1 (A), SW1.2 (B), TP6.1
unnamed: C44.1, D4.1 (A), F2.1, SW1.4 (A), SW1.5 (B), TP7.1
unnamed: D5.1 (K), R22.1
unnamed: F1.2, J8.1
unnamed: F2.2, J8.4

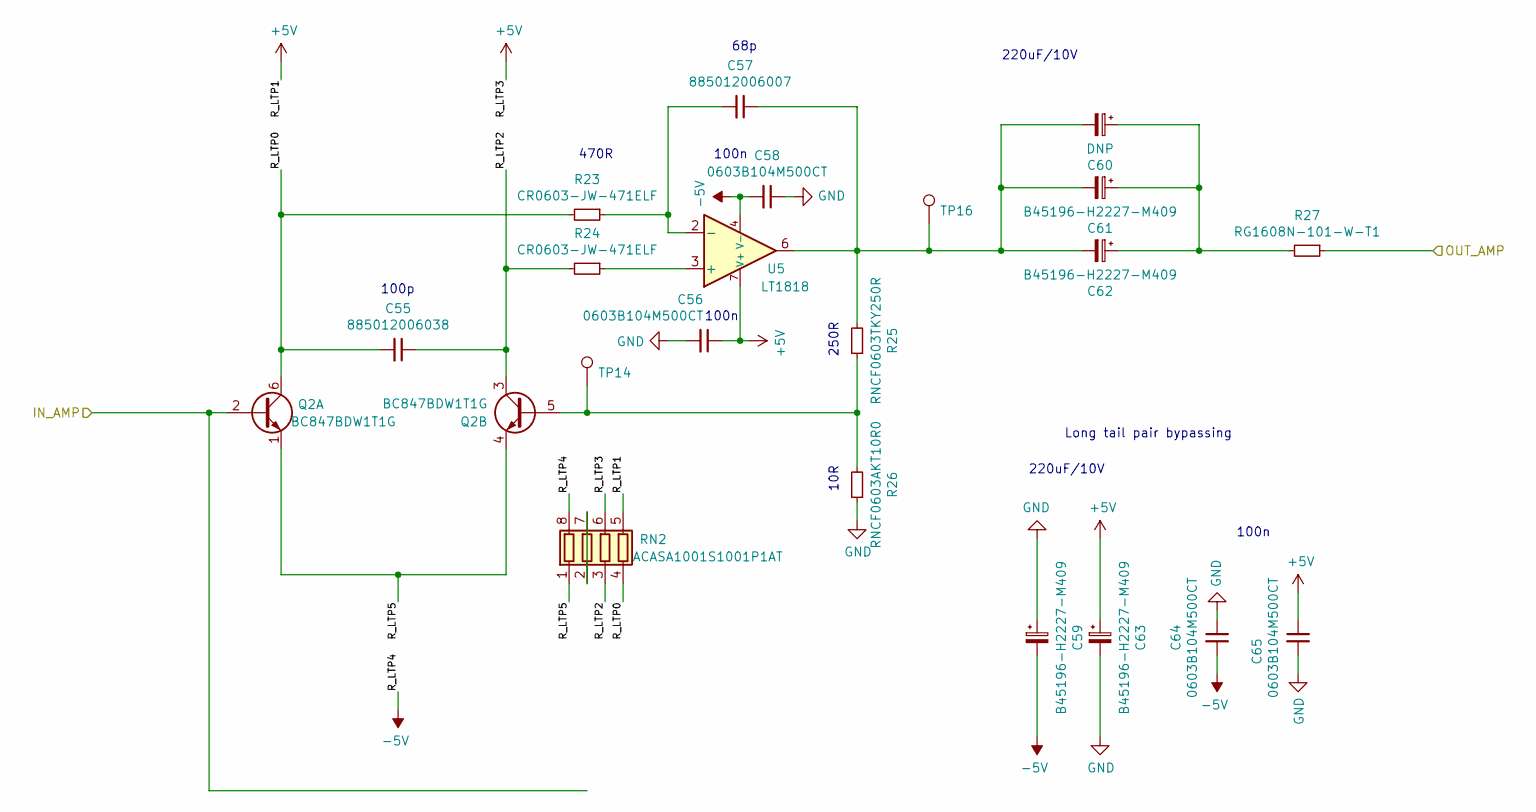
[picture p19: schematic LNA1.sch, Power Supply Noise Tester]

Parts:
C55: 885012006038; R_0603_1608Metric
C56, C58, C64, C65: 0603B104M500CT; R_0603_1608Metric
C57: 885012006007; R_0603_1608Metric
C59, C61, C62, C63: B45196-H2227-M409; CP_EIA-7343-31_Kemet-D
C60: DNP; CP_EIA-7343-31_Kemet-D
Q2: BC847BDW1T1G; SOT-363_SC-70-6
R23, R24: CR0603-JW-471ELF; R_0603_1608Metric
R25: RNCF0603TKY250R; R_0603_1608Metric
R26: RNCF0603AKT10R0; R_0603_1608Metric
R27: RG1608N-101-W-T1; R_0603_1608Metric
RN2: ACASA1001S1001P1AT; R_Array_Convex_4x1206
TP14, TP16: TestPoint; TestPoint_THTPad_D1.0mm_Drill0.5mm
U5: LT1818; SOIC-8-LINEAR

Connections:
+5V: C56.1, C63.1, C65.1, RN2.5 (R4.2), RN2.6 (R3.2), U5.7 (V+); also elsewhere on the board
-5V: C58.2, C59.2, C64.2, RN2.8 (R1.2), U5.4 (V-); also elsewhere on the board
/GainBlock/GB_IN: R27.1; also elsewhere on the board
/InputAmplifier/IN_AMP: Q2.2 (B1); also elsewhere on the board
/LNA1/R_LTP0: C55.2, Q2.6 (C1), R23.2, RN2.4 (R4.1)
/LNA1/R_LTP2: C55.1, Q2.3 (C2), R24.2, RN2.3 (R3.1)
/LNA1/R_LTP5: Q2.1 (E1), Q2.4 (E2), RN2.1 (R1.1)
GND: C56.2, C58.1, C59.1, C63.2, C64.1, C65.2, R26.1; also elsewhere on the board
unnamed: C57.1, C60.2, C61.2, C62.2, R25.2, TP16.1, U5.6
unnamed: C57.2, R23.1, U5.2 (-)
unnamed: C60.1, C61.1, C62.1, R27.2
unnamed: Q2.5 (B2), R25.1, R26.2, TP14.1
unnamed: R24.1, U5.3 (+)

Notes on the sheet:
250R
10R
470R
100p
68p
100n
220uF/10V
Long tail pair bypassing

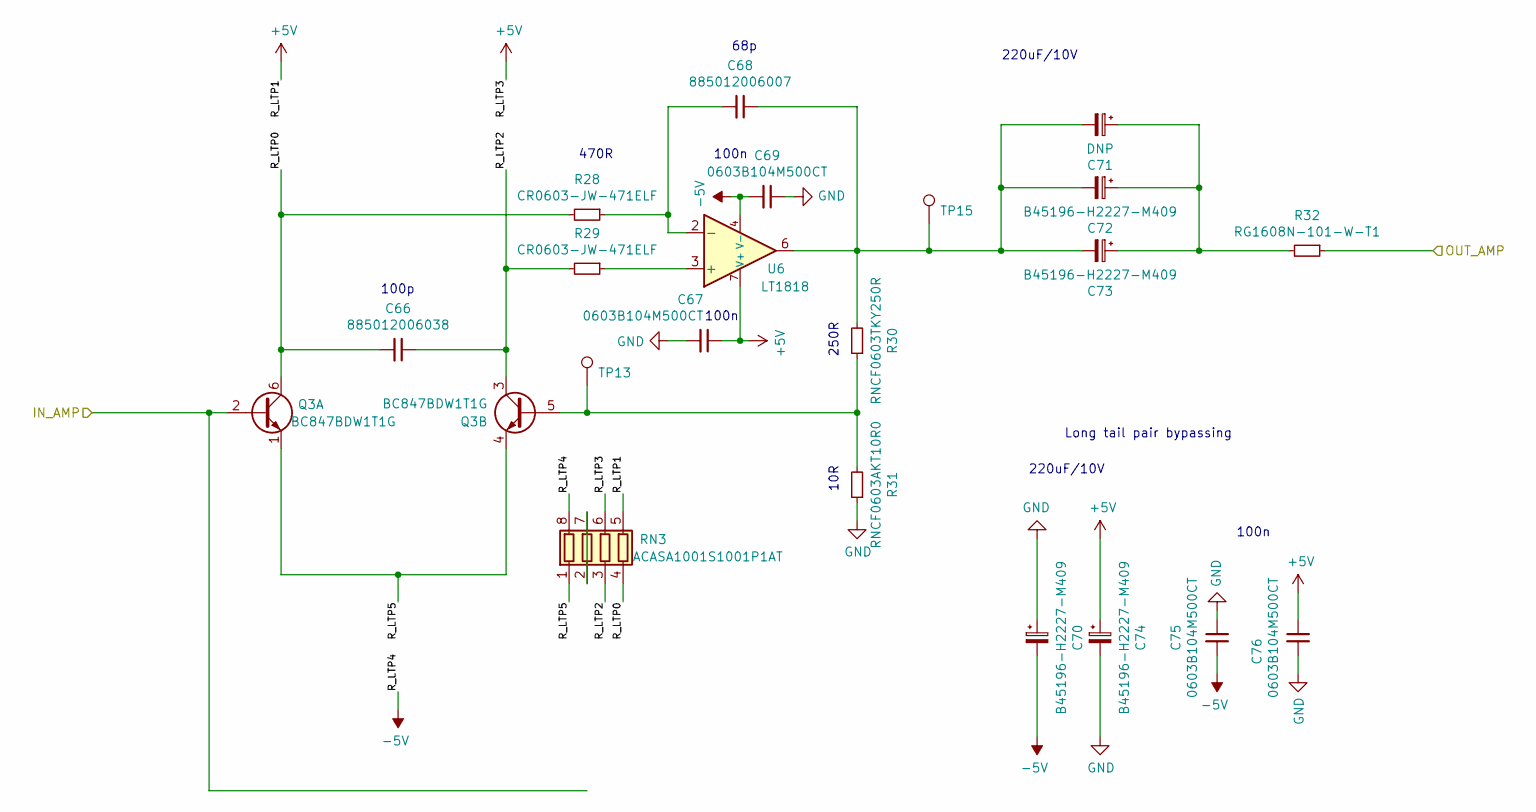
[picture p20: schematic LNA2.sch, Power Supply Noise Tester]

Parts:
C66: 885012006038; R_0603_1608Metric
C67, C69, C75, C76: 0603B104M500CT; R_0603_1608Metric
C68: 885012006007; R_0603_1608Metric
C70, C72, C73, C74: B45196-H2227-M409; CP_EIA-7343-31_Kemet-D
C71: DNP; CP_EIA-7343-31_Kemet-D
Q3: BC847BDW1T1G; SOT-363_SC-70-6
R28, R29: CR0603-JW-471ELF; R_0603_1608Metric
R30: RNCF0603TKY250R; R_0603_1608Metric
R31: RNCF0603AKT10R0; R_0603_1608Metric
R32: RG1608N-101-W-T1; R_0603_1608Metric
RN3: ACASA1001S1001P1AT; R_Array_Convex_4x1206
TP13, TP15: TestPoint; TestPoint_THTPad_D1.0mm_Drill0.5mm
U6: LT1818; SOIC-8-LINEAR

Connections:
+5V: C67.1, C74.1, C76.1, RN3.5 (R4.2), RN3.6 (R3.2), U6.7 (V+); also elsewhere on the board
-5V: C69.2, C70.2, C75.2, RN3.8 (R1.2), U6.4 (V-); also elsewhere on the board
/GainBlock/GB_IN: R32.1; also elsewhere on the board
/InputAmplifier/IN_AMP: Q3.2 (B1); also elsewhere on the board
/LNA2/R_LTP0: C66.2, Q3.6 (C1), R28.2, RN3.4 (R4.1)
/LNA2/R_LTP2: C66.1, Q3.3 (C2), R29.2, RN3.3 (R3.1)
/LNA2/R_LTP5: Q3.1 (E1), Q3.4 (E2), RN3.1 (R1.1)
GND: C67.2, C69.1, C70.1, C74.2, C75.1, C76.2, R31.1; also elsewhere on the board
unnamed: C68.1, C71.2, C72.2, C73.2, R30.2, TP15.1, U6.6
unnamed: C68.2, R28.1, U6.2 (-)
unnamed: C71.1, C72.1, C73.1, R32.2
unnamed: Q3.5 (B2), R30.1, R31.2, TP13.1
unnamed: R29.1, U6.3 (+)

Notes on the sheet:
250R
10R
470R
100p
68p
100n
220uF/10V
Long tail pair bypassing

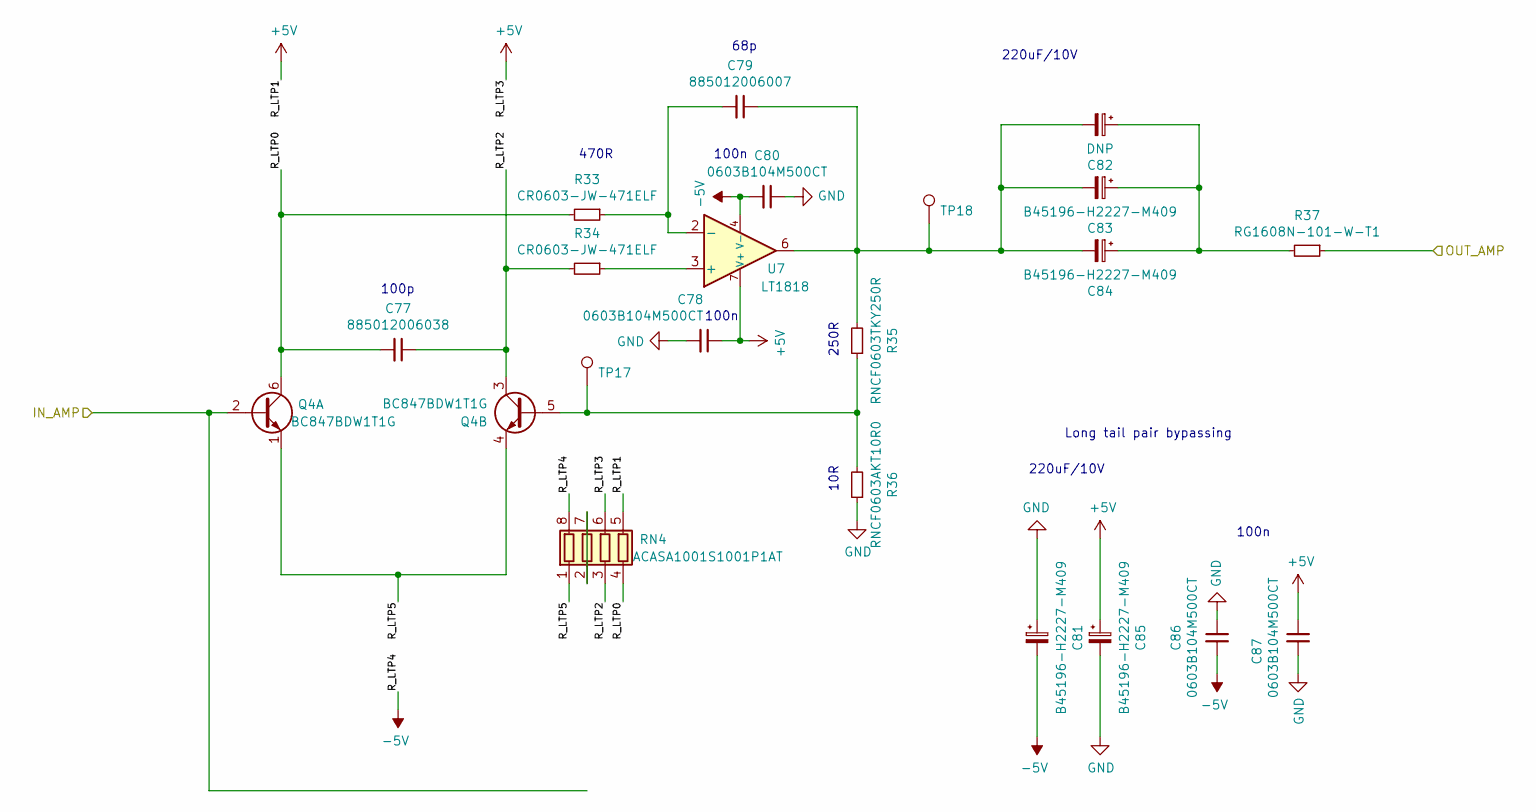
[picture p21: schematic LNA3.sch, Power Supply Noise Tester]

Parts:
C77: 885012006038; R_0603_1608Metric
C78, C80, C86, C87: 0603B104M500CT; R_0603_1608Metric
C79: 885012006007; R_0603_1608Metric
C81, C83, C84, C85: B45196-H2227-M409; CP_EIA-7343-31_Kemet-D
C82: DNP; CP_EIA-7343-31_Kemet-D
Q4: BC847BDW1T1G; SOT-363_SC-70-6
R33, R34: CR0603-JW-471ELF; R_0603_1608Metric
R35: RNCF0603TKY250R; R_0603_1608Metric
R36: RNCF0603AKT10R0; R_0603_1608Metric
R37: RG1608N-101-W-T1; R_0603_1608Metric
RN4: ACASA1001S1001P1AT; R_Array_Convex_4x1206
TP17, TP18: TestPoint; TestPoint_THTPad_D1.0mm_Drill0.5mm
U7: LT1818; SOIC-8-LINEAR

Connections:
+5V: C78.1, C85.1, C87.1, RN4.5 (R4.2), RN4.6 (R3.2), U7.7 (V+); also elsewhere on the board
-5V: C80.2, C81.2, C86.2, RN4.8 (R1.2), U7.4 (V-); also elsewhere on the board
/GainBlock/GB_IN: R37.1; also elsewhere on the board
/InputAmplifier/IN_AMP: Q4.2 (B1); also elsewhere on the board
/LNA3/R_LTP0: C77.2, Q4.6 (C1), R33.2, RN4.4 (R4.1)
/LNA3/R_LTP2: C77.1, Q4.3 (C2), R34.2, RN4.3 (R3.1)
/LNA3/R_LTP5: Q4.1 (E1), Q4.4 (E2), RN4.1 (R1.1)
GND: C78.2, C80.1, C81.1, C85.2, C86.1, C87.2, R36.1; also elsewhere on the board
unnamed: C79.1, C82.2, C83.2, C84.2, R35.2, TP18.1, U7.6
unnamed: C79.2, R33.1, U7.2 (-)
unnamed: C82.1, C83.1, C84.1, R37.2
unnamed: Q4.5 (B2), R35.1, R36.2, TP17.1
unnamed: R34.1, U7.3 (+)

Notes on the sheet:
250R
10R
470R
100p
68p
100n
220uF/10V
Long tail pair bypassing

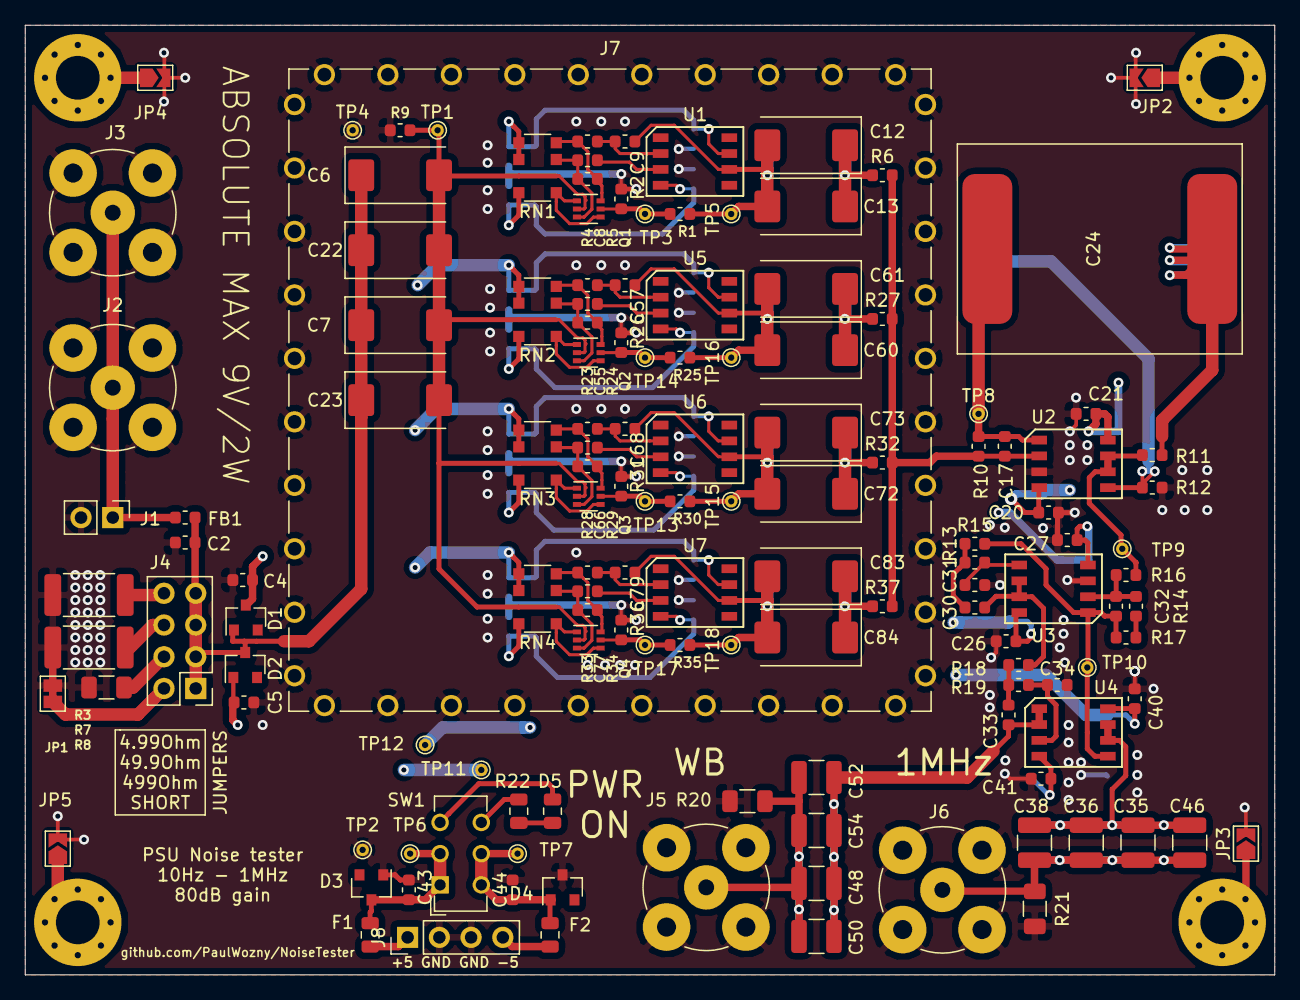
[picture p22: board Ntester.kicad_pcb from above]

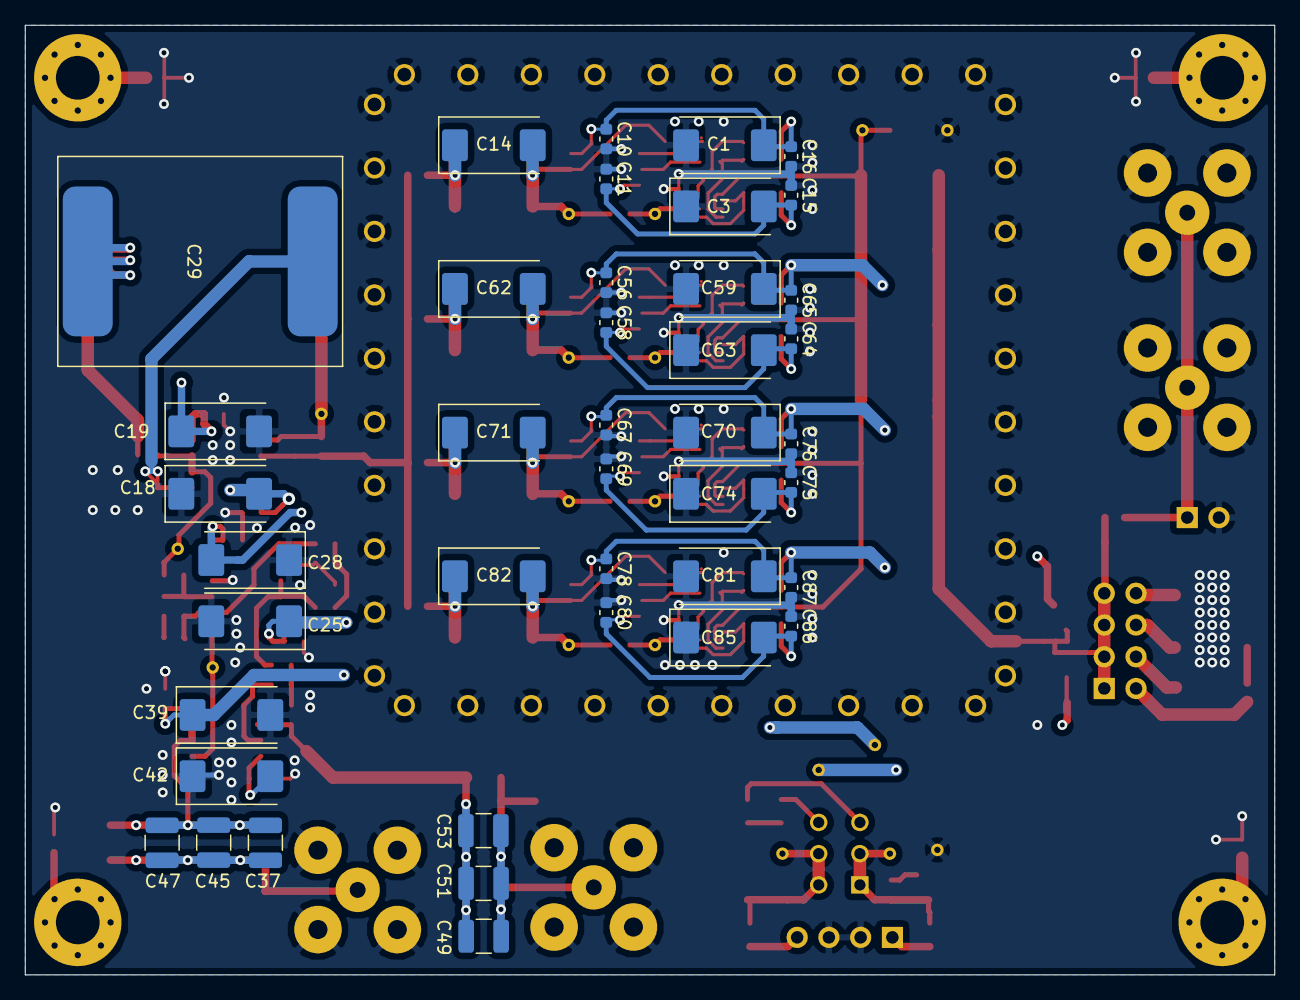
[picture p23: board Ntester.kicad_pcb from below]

Board: 4 copper layers, 100.0 x 76.0 mm, 183 parts (41 on the bottom side), 68 nets.

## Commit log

2018-10-19 added basic schematic
    [ADC.sch, AFE.sch, BMS.sch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]
2018-10-29 added rest of files
    [ADC.sch, AFE.sch, BMS.sch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]
2018-11-01 " alomost" finalized layout
    [GBlock.sch, InAmp.sch, InStage.sch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]
2018-11-02 layout finalized
    [GBlock.sch, InAmp.sch, InAmp2.sch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]
2018-11-07 BOM was updated
    [InAmp.sch, LNA1.sch, LNA2.sch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]
2018-11-14 changed BOM
    [Ntester.csv]
2018-11-27 Cleanup and update of repo
    [FBlock.sch, GBlock.sch, InAmp.sch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]
